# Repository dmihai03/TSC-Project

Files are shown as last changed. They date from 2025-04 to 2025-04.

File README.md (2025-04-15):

# eBook reader - Pacuraru Mihai Dorin
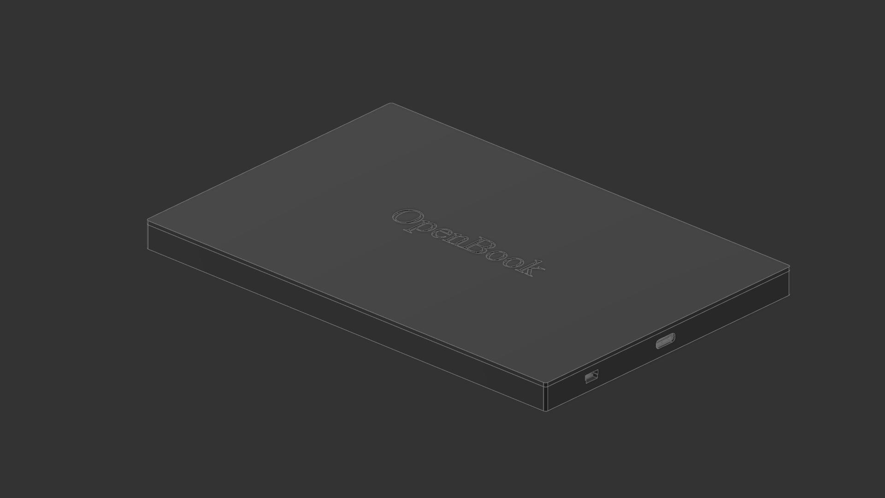
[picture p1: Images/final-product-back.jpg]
final product


This product is an eBook reader that uses an **ESP32-C6** microcontroller powered by an **USB Type-C**.

 Implementation steps:
    - create 2D schematic
    - create 2D PCB, solving routing errors
    - add 3D model to every component 
    - pushed 2D PCB to 3D
    - created 3D model for battery
    - imported display model
    - build the final 3D model of product

---

## Block Diagram
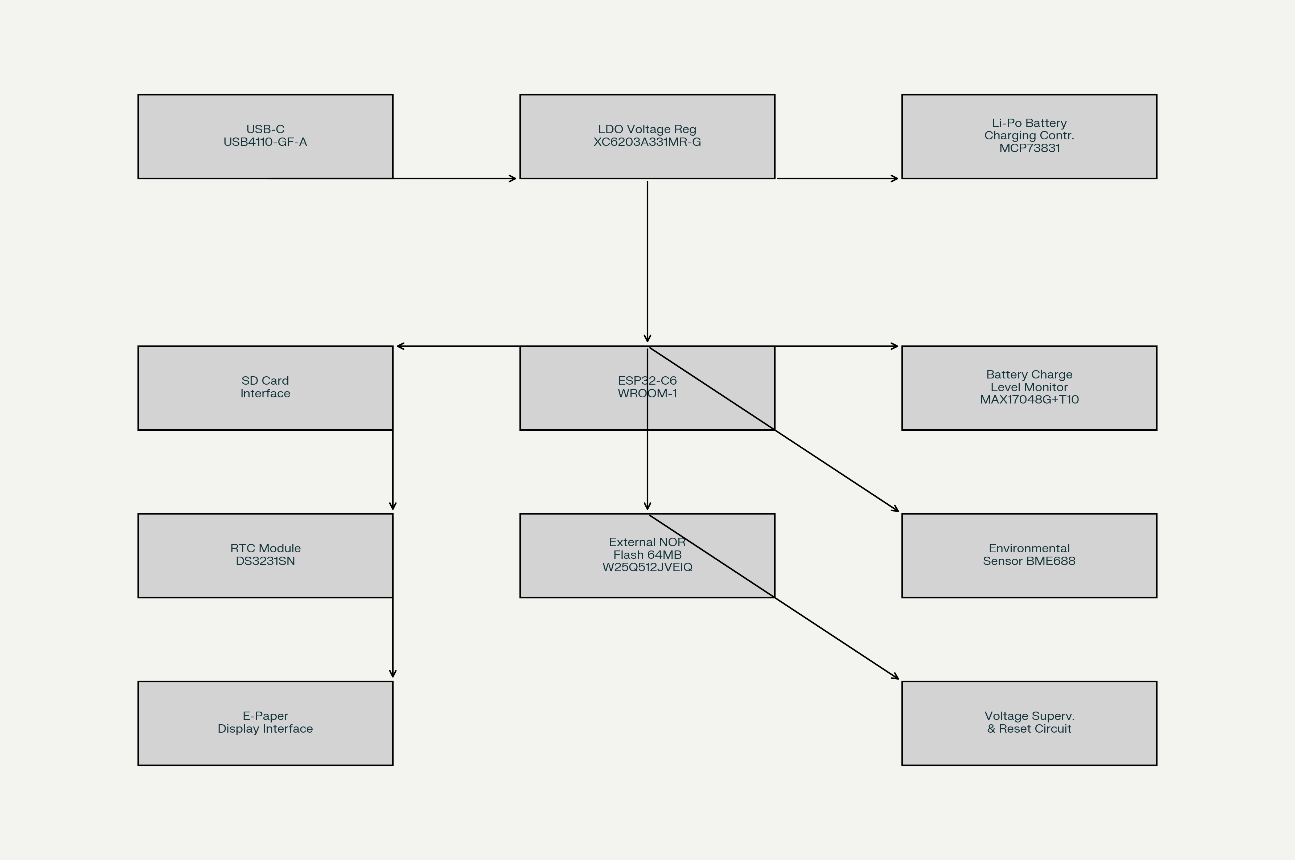
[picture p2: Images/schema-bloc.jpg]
block diagram


---

## Hardware functionalities

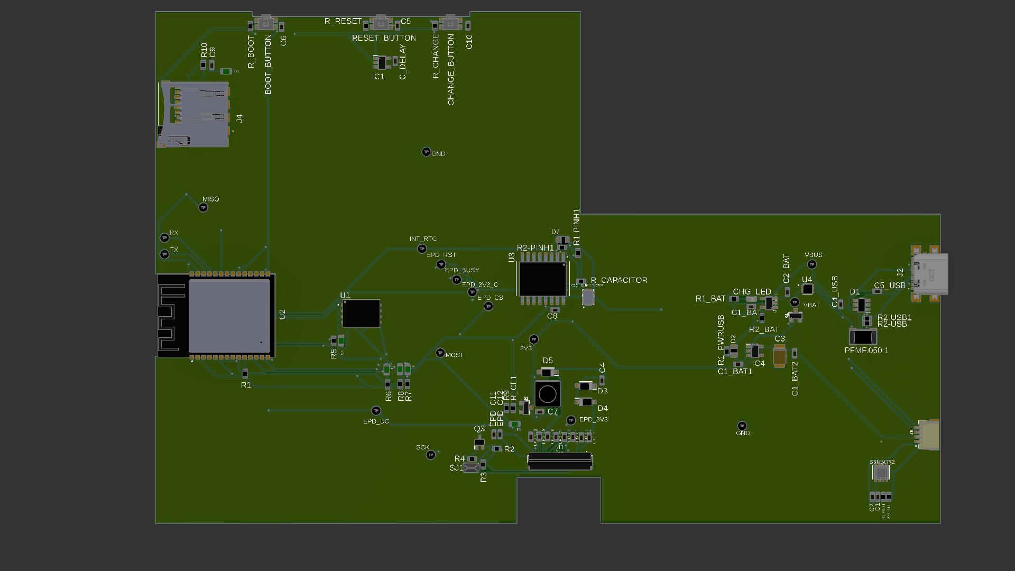
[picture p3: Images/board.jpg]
board


### ESP32-C6 microcontroller

The ESP32-C6 microcontroller has a single core SoC RISC-V that supports:
  - WiFi6, Bluetooth 5, Zigbee and Thread
  - integrated flash memory up to 8 MB
  - 23 GPIO pins
  - SPI, 12C, UART, I2S, USB interfaces support

Charging and energy management:
  - USB-C that uses USB4110-GF-A connector with ESD protection for battery charging
  - LiPo battery that gets charged with the help of MCP73831 controller
  - the integrated circuit MAX17048G+T10 for monitorizing battery charging level via I2C interface

Display system:
  - E-Paper driver interface connected to microcontroller via SPI

Memory:
  - microSD card interface connected via SPI for heavy data

Buttons:
  - BOOT -> the microcontroller enters in bootloader
  - RESET -> general reset
  - I/O CHANGE -> user I/O interactions

### ESP32-C6 pins configuration
| Component | PIN |
|----|----|
|Display SPI | MOSI, CLK, CS, DC |
|BME688 | SDA, SCL, I2C |
|Buttons | GPIO1, GPIO2, GPIO3 |
|USB-C | D+, D-, VBUS |

---
## Bill of Materials (BOM)
| Component | Buy | Datasheet |
| --- | --- | --- |
| PFMF.050.1 | [Retailer](https://ro.mouser.com/ProductDetail/Schurter/PFMF.050.2?qs=1auRipcfynCums5v1iucSA%3D%3D) |  [Datasheet](https://ro.mouser.com/datasheet/2/358/typ_PFMF-1275918.pdf) |
| USB4110-GF-A | [Retailer](https://ro.mouser.com/ProductDetail/GCT/USB4110-GF-A?qs=KUoIvG%2F9IlYiZvIXQjyJeA%3D%3D) | [Datasheet](https://ro.mouser.com/datasheet/2/837/GCT_USB4110_Product_Drawing___20k_cycles-3455479.pdf) |
| USBLC6-2SC6Y | [Retailer](https://ro.mouser.com/ProductDetail/STMicroelectronics/USBLC6-2SC6Y?qs=gNDSiZmRJS%2FOgDexvXkdow%3D%3D) | [Datasheet](https://ro.mouser.com/datasheet/2/389/usblc6_2sc6y-1852505.pdf) |
| SD0805S020S1R0 | [Retailer](https://ro.mouser.com/ProductDetail/KYOCERA-AVX/SD0805S020S1R0?qs=jCA%252BPfw4LHbpkAoSnwrdjw%3D%3D) | [Datasheet](https://ro.mouser.com/datasheet/2/40/schottky-3165252.pdf) |
| DMG2305UX-7 | [Retailer](https://ro.mouser.com/ProductDetail/Diodes-Incorporated/DMG2305UX-7?qs=L1DZKBg7t5F%2FNBHrjfxC%252Bg%3D%3D) | [Datasheet](https://www.diodes.com/assets/Datasheets/DMG2305UX.pdf) |
| XC6220A331MR-G | [Retailer](https://ro.mouser.com/ProductDetail/Torex-Semiconductor/XC6220A331MR-G?qs=AsjdqWjXhJ8ZSWznL1J0gg%3D%3D) | [Datasheet](https://ro.mouser.com/datasheet/2/760/xc6220-3371556.pdf) |
| Condensator 100 uF TANT | [Retailer](https://ro.mouser.com/ProductDetail/KYOCERA-AVX/TAJW107M010RNJ?qs=Wtp%252Bf%2FAeVqIH8v1VxV%252B1Rg%3D%3D) | [Datasheet](https://ro.mouser.com/datasheet/2/40/TAJ-3165264.pdf) |
| 112A-TAAR-R03_ATTEND | [Retailer](https://www.digikey.ro/en/products/detail/attend-technology/112A-TAAR-R03/17633923) | [Datasheet](https://www.attend.com.tw/data/download/file/112A-TAAR-R03_Spec.pdf)
| ESP32-C6-WROOM-1-N8 | [Retailer](https://ro.mouser.com/ProductDetail/Espressif-Systems/ESP32-C6-WROOM-1-N8?qs=8Wlm6%252BaMh8ST02Gmwp74cw%3D%3D) | [Datasheet](https://ro.mouser.com/datasheet/2/891/Espressif_ESP32_C6_WROOM_1__Datasheet_V0_1_PRELIMI-3239987.pdf) |
| MCP73831 | [Retailer](https://ro.mouser.com/ProductDetail/Microchip-Technology/MCP73831T-2ACI-OT?qs=yUQqVecv4qvbBQBGbHx0Mw%3D%3D) | [Datasheet](https://ro.mouser.com/datasheet/2/268/MCP73831_Family_Data_Sheet_DS20001984H-3441711.pdf) |
| CHG_LED | [Retailer](https://store.comet.srl.ro/Catalogue/Product/40478/) | [Datasheet](https://www.snapeda.com/parts/KP-1608SURCK/Kingbright/datasheet/) |
| SI1308EDL-T1-GE3 | [Retailer](https://ro.mouser.com/ProductDetail/Vishay-Semiconductors/SI1308EDL-T1-GE3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) | [Datasheet](https://www.vishay.com/doc?63399) |
| MBR0530 | [Retailer](https://ro.mouser.com/ProductDetail/Micro-Commercial-Components-MCC/MBR0530-T?qs=9VyI4qLX4NTSXkb9ynzJnA%3D%3D) | [Datasheet](https://ro.mouser.com/datasheet/2/258/mcc_mbr0520~mbr0560sod123-1179695.pdf) |
| L1 | [Retailer](https://ro.mouser.com/ProductDetail/Wurth-Elektronik/744043680?qs=PGXP4M47uW6VkZq%252BkzjrHA%3D%3D) | [Datasheet](https://www.we-online.com/components/products/datasheet/744043680.pdf) |
| FH34SRJ-24S-0.5SH_99_ | [Retailer](https://ro.mouser.com/ProductDetail/Hirose-Connector/FH34SRJ-24S-0.5SH99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) | [Datasheet](https://ro.mouser.com/datasheet/2/185/FH34SRJ_24S_0_5SH_99__CL0580_1255_6_99_2DDrawing_0-1615044.pdf) |
| BME688 | [Retailer](https://ro.mouser.com/ProductDetail/Bosch-Sensortec/BME688?qs=IS%252B4QmGtzzqQoVDscqwx3A%3D%3D) | [Datasheet](https://ro.mouser.com/datasheet/2/783/bst_bme688_fl000-2307034.pdf) |
| BD5229G-TR | [Retailer](https://ro.mouser.com/ProductDetail/ROHM-Semiconductor/BD5229G-TR?qs=4kLU8WoGk0vvnhrrYwdszw%3D%3D) | [Datasheet](https://fscdn.rohm.com/en/products/databook/datasheet/ic/power/voltage_detector/bd52xxg-e.pdf) |
| Button | [Retailer](https://ro.mouser.com/ProductDetail/CK/KMR221GULCLFS?qs=u2NJ%252B70r0goBXaNk7IrU0Q%3D%3D) | [Datasheet](https://www.ckswitches.com/media/1479/kmr2.pdf) |
| MAX17048G+T10 | [Retailer](https://ro.mouser.com/ProductDetail/Analog-Devices-Maxim-Integrated/MAX17048G%2bT10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) | [Datasheet](https://ro.mouser.com/datasheet/2/609/MAX17048_MAX17049-3469099.pdf) |
| W25Q512JVEIQ | [Retailer](https://ro.mouser.com/ProductDetail/Winbond/W25Q512JVEIQ?qs=l7cgNqFNU1jw6svr3at6tA%3D%3D) | [Datasheet](https://ro.mouser.com/datasheet/2/949/Winbond_W25Q512JV_Datasheet-3240039.pdf) |
| PGB1010603MR | [Retailer](https://ro.mouser.com/ProductDetail/Littelfuse/PGB1010603MRHF?qs=KvZd0dN2Zg%2FuIq6icj%252BGKA%3D%3D) | [Datasheet](https://www.littelfuse.com/media?itemid=8a337998-d54d-466b-be4e-dc5bcd1f9321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) |
| QWIIC_RIGHT_ANGLE | [Retailer](https://ro.mouser.com/ProductDetail/GCT/USB4110-GF-A?qs=KUoIvG%2F9IlYiZvIXQjyJeA%3D%3D) | [Datasheet](https://ro.mouser.com/datasheet/2/837/GCT_USB4110_Product_Drawing___20k_cycles-3455479.pdf) |
| DS3231SN# | [Retailer](https://ro.mouser.com/ProductDetail/Analog-Devices-Maxim-Integrated/DS3231SN?qs=ffX8NcjNb2RmKAb9wAk9Ug%3D%3D) | [Datasheet](https://ro.mouser.com/datasheet/2/609/DS3231-3421123.pdf) |
| CPH3225A C10_SUPERCAP | [Retailer](https://ro.mouser.com/ProductDetail/Seiko-Semiconductors/CPH3225A?qs=3etwrb1wR%252BhUOph6lAO7eg%3D%3D) | [Datasheet](https://ro.mouser.com/datasheet/2/360/Seiko_Instruments_MicroBattery_E_20230330_2024Jan_-3561061.pdf) |
| Condensator 100nF | [Retailer](https://ro.mouser.com/ProductDetail/KYOCERA-AVX/06033G104ZAT2A?qs=NXubJDmysXJMPmHfVo6Z%252BA%3D%3D) | [Datasheet](https://ro.mouser.com/datasheet/2/40/KGM_Y5V-3223189.pdf) |
| Condensator 4.7uF | [Retailer](https://ro.mouser.com/ProductDetail/KYOCERA-AVX/0402ZD475MAT2A?qs=NBFAU1oqP4W4U2PCPHI0sg%3D%3D) | [Datasheet](https://ro.mouser.com/datasheet/2/40/cx5r_KGM-3223198.pdf) |
| Condensator 10uF | [Retailer](https://ro.mouser.com/ProductDetail/Samsung-Electro-Mechanics/CL10A106KQ8NNNL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) | [Datasheet](https://ro.mouser.com/datasheet/2/585/MLCC-1837944.pdf) |
| Condensator 1uF/50V | [Retailer](https://ro.mouser.com/ProductDetail/KYOCERA-AVX/06035D105MAT2A?qs=k4kUdCzLgS5%252BURKe1SOIeQ%3D%3D) | [Datasheet](https://ro.mouser.com/datasheet/2/40/cx5r_KGM-3223198.pdf) |
| Resistor 10K | [Retailer](https://ro.mouser.com/ProductDetail/Vishay-Beyschlag/MCS0402MD1002BE000?qs=17u8i%2FzlE8%2F9BrAaXkMk1w%3D%3D) | [Datasheet](https://www.vishay.com/doc?28952) |
| Resistor 200 | [Retailer](https://ro.mouser.com/ProductDetail/Vishay-Beyschlag/MCS0402MD2000BE100?qs=3SvaY9RawMJNVte4F12%252BZQ%3D%3D) | [Datasheet](https://www.vishay.com/doc?28952) |
| Resistor 100K | [Retailer](https://ro.mouser.com/ProductDetail/Vishay-Beyschlag/MCT0603PD1003DP500?qs=5aG0NVq1C4wWAn8Ei3OpZA%3D%3D) | [Datasheet](https://www.vishay.com/doc?28916) |
| Resistor 2.2 | [Retailer](https://ro.mouser.com/ProductDetail/SEI-Stackpole/RMCF0402FT2R20?qs=IPgv5n7u5QbBgyl0jwhwsA%3D%3D) | [Datasheet](https://ro.mouser.com/datasheet/2/385/SEI_RMCF_RMCP-3077565.pdf) |
| Resistor 5K1| [Retailer](https://www.venkel.com/part/TFCR0603-16W-K-5690FT) | [Datasheet](https://data.venkel.com/documents/tfcr-series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.) |
| Resistor 2K | [Retailer](https://ro.mouser.com/ProductDetail/Vishay-Beyschlag/MCS04020C2001FE000?qs=wTZ%2FFzl837YG0wIkZJJOwQ%3D%3D) | [Datasheet](https://www.vishay.com/doc?28705) |
| Resistor 0.47 | [Retailer](https://ro.mouser.com/ProductDetail/SEI-Stackpole/CSR0402JKR470?qs=IPgv5n7u5QawIB6nBEt8wA%3D%3D) | [Datasheet](https://ro.mouser.com/datasheet/2/385/SEI_CSR_CSRN-3077593.pdf) |
| Resistor 15 | [Retailer](https://ro.mouser.com/ProductDetail/YAGEO/RT0402FRE0715RL?qs=BXCcY9r%252B08DFFpLSkPOIqQ%3D%3D) | [Datasheet](https://ro.mouser.com/datasheet/2/447/PYu_RT_1_to_0_01_RoHS_L_15-3461507.pdf) |

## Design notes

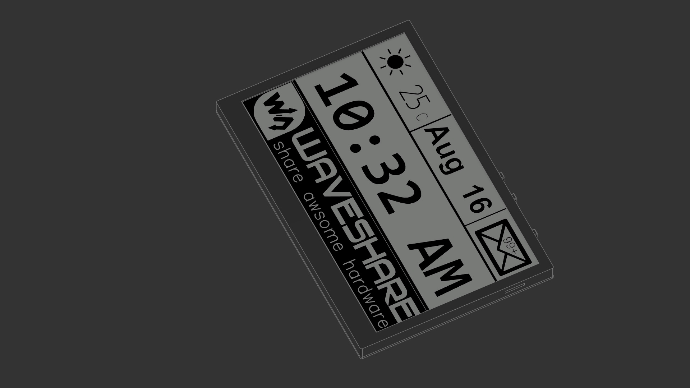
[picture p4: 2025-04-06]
Images/final-product-front.jpg

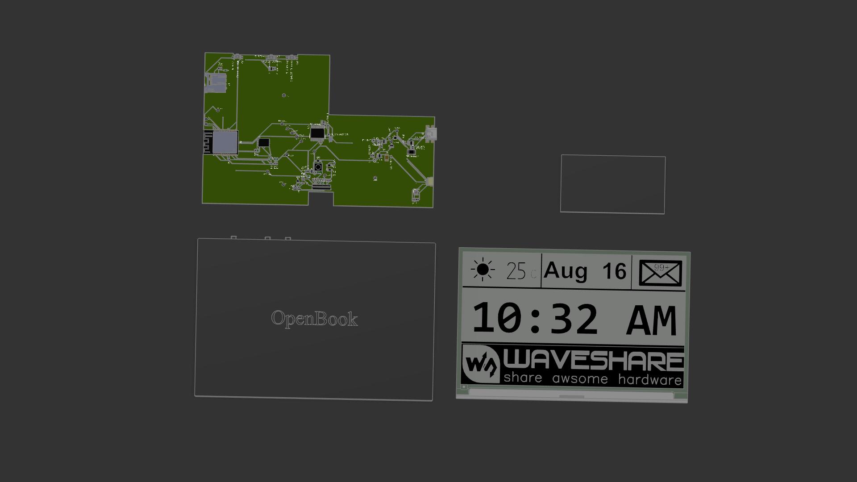
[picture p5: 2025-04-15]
Images/exploded-view.jpg

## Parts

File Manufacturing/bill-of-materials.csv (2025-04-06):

Qty | Value | Device | Package | Parts | Description | ARROW_PART_NUMBER | ARROW_PRICE-STOCK | AVAILABILITY | CENTROID_NOT_SPECIFIED | CHECK_PRICES | COPYRIGHT | DATASHEET | DESCRIPTION | DIGIKEY_DESCRIPTION | DIGIKEY_PART_NUMBER | HEIGHT | LEAD_FREE | MANUFACTURER_NAME | MANUFACTURER_PART_NUMBER | MF | MFR_NAME | MOUSER_PART_NUMBER | MOUSER_PRICE-STOCK | MOUSER_TESTING_PART_NUMBER | MOUSER_TESTING_PRICE-STOCK | MP | MPN | PACKAGE | POPULARITY | PREFIX | PRICE | PROD_ID | PURCHASE-URL | ROHS | SNAPEDA_LINK | SPICEMODEL | SPICEPREFIX | TEMPERATURE_RANGE_HIGH | TEMPERATURE_RANGE_LOW | TP_SIGNAL_NAME | VALUE | VALUE_V
1 |  | ADAFRUIT_LEDCHIP-LED0603 | ADAFRUIT_CHIP-LED0603 | CHG_LED | LED
1 |  | ESP32C6_VARISTORCN1812 | ESP32C6_VARISTOR_CT/CN1812 | PFMF.050.1 | VARISTOR |  |  |  |  |  |  |  |  |  |  |  |  |  |  |  |  |  |  |  |  |  |  |  | 0
1 |  | SAMACSYS_PARTS_USB4110-GF-A | SAMACSYS_PARTS_USB4110GFA | J2 | CONN USB 2.0 TYPE-C R/A SMT |  |  |  |  |  |  |  | CONN USB 2.0 TYPE-C R/A SMT |  |  | 3.26mm |  | GCT (GLOBAL CONNECTOR TECHNOLOGY) | USB4110-GF-A |  |  | 640-USB4110-GF-A | https://www.mouser.co.uk/ProductDetail/GCT/USB4110-GF-A?qs=KUoIvG%2F9IlYiZvIXQjyJeA%3D%3D
1 |  | SJ | SJ | SJ1 | SMD solder JUMPER |  |  |  |  |  |  |  |  |  |  |  |  |  |  |  |  |  |  |  |  |  |  |  | 3
1 | 0.1uF/50V | ESP32_WROVER_EAGLE-LTSPICE_CC0402 | ESP32_WROVER_EAGLE-LTSPICE_C0402 | EPD_C5 | CAPACITOR, European symbol |  |  |  |  |  |  |  |  |  |  |  |  |  |  |  |  |  |  |  |  |  |  |  |  |  |  |  |  |  |  | NONE | C
1 | 0.47 | ESP32_WROVER_EAGLE-LTSPICE_RR0402 | ESP32_WROVER_EAGLE-LTSPICE_R0402 | R3 | RESISTOR, European symbol |  |  |  |  |  |  |  |  |  |  |  |  |  |  |  |  |  |  |  |  |  |  |  |  |  |  |  |  |  |  | NONE | R
1 | 100K | ESP32_WROVER_EAGLE-LTSPICE_RR0402 | ESP32_WROVER_EAGLE-LTSPICE_R0402 | R1_PWRUSB | RESISTOR, European symbol |  |  |  |  |  |  |  |  |  |  |  |  |  |  |  |  |  |  |  |  |  |  |  |  |  |  |  |  |  |  |  | R
1 | 100nF | EAGLE-LTSPICE_CC0402 | ESP32_WROVER_EAGLE-LTSPICE_C0402 | C9 | CAPACITOR, European symbol |  |  |  |  |  |  |  |  |  |  |  |  |  |  |  |  |  |  |  |  |  |  |  |  |  |  |  |  |  |  | NONE | C
8 | 100nF | ESP32_WROVER_EAGLE-LTSPICE_CC0402 | ESP32_WROVER_EAGLE-LTSPICE_C0402 | C1, C2, C4_USB, C5_USB, C6, C8, C10, C_DELAY | CAPACITOR, European symbol |  |  |  |  |  |  |  |  |  |  |  |  |  |  |  |  |  |  |  |  |  |  |  |  |  |  |  |  |  |  | NONE | C
1 | 100uF TANT | RCL_CPOL-EUCT3528 | RCL_CT3528 | C3 | POLARIZED CAPACITOR, European symbol |  |  |  |  |  |  |  |  |  |  |  |  |  |  |  |  |  |  |  |  |  |  |  | 0 |  |  |  |  |  |  |  | C
15 | 10K | ESP32_WROVER_EAGLE-LTSPICE_RR0402 | ESP32_WROVER_EAGLE-LTSPICE_R0402 | R1, R1-PINH, R1-PINH1, R2-PINH, R2-PINH1, R5, R6, R7, R8, R9, R10, R_BOOT, R_CHANGE, R_CL1, R_RESET | RESISTOR, European symbol |  |  |  |  |  |  |  |  |  |  |  |  |  |  |  |  |  |  |  |  |  |  |  |  |  |  |  |  |  |  | NONE | R
1 | 10k | ESP32_WROVER_EAGLE-LTSPICE_RR0402 | ESP32_WROVER_EAGLE-LTSPICE_R0402 | R4 | RESISTOR, European symbol |  |  |  |  |  |  |  |  |  |  |  |  |  |  |  |  |  |  |  |  |  |  |  |  |  |  |  |  |  |  | NONE | R
1 | 10uF | ESP32_WROVER_EAGLE-LTSPICE_CC0402 | ESP32_WROVER_EAGLE-LTSPICE_C0402 | C7 | CAPACITOR, European symbol |  |  |  |  |  |  |  |  |  |  |  |  |  |  |  |  |  |  |  |  |  |  |  |  |  |  |  |  |  |  | NONE | C
1 | 112A-TAAR-R03_ATTEND | 112A-TAAR-R03_ATTEND | 112ATAARR03ATTEND | J4 | Micro SD Card Socket, Push-Push Type, Top Mount, SMT, H=1.83mm, 10u |  |  |  |  |  |  |  | Micro SD Card Socket | Push-Push Type | Top Mount | SMT | H=1.83mm | 10u |  |  | 1.9mm |  | ATTEND | 112A-TAAR-R03 ATTEND
1 | 15 | ESP32_WROVER_EAGLE-LTSPICE_RR0402 | ESP32_WROVER_EAGLE-LTSPICE_R0402 | R_CAPACITOR | RESISTOR, European symbol |  |  |  |  |  |  |  |  |  |  |  |  |  |  |  |  |  |  |  |  |  |  |  |  |  |  |  |  |  |  | NONE | R
1 | 1uF | ESP32_WROVER_EAGLE-LTSPICE_CC0402 | ESP32_WROVER_EAGLE-LTSPICE_C0402 | C5 | CAPACITOR, European symbol |  |  |  |  |  |  |  |  |  |  |  |  |  |  |  |  |  |  |  |  |  |  |  |  |  |  |  |  |  |  | NONE | C
9 | 1uF/50V | ESP32_WROVER_EAGLE-LTSPICE_CC0402 | ESP32_WROVER_EAGLE-LTSPICE_C0402 | EPD_C1, EPD_C2, EPD_C6, EPD_C7, EPD_C8, EPD_C9, EPD_C10, EPD_C11, EPD_C12 | CAPACITOR, European symbol |  |  |  |  |  |  |  |  |  |  |  |  |  |  |  |  |  |  |  |  |  |  |  |  |  |  |  |  |  |  | NONE | C
1 | 2.2 | ESP32_WROVER_EAGLE-LTSPICE_RR0402 | ESP32_WROVER_EAGLE-LTSPICE_R0402 | R2 | RESISTOR, European symbol |  |  |  |  |  |  |  |  |  |  |  |  |  |  |  |  |  |  |  |  |  |  |  |  |  |  |  |  |  |  | NONE | R
1 | 200 | ESP32_WROVER_EAGLE-LTSPICE_RR0402 | ESP32_WROVER_EAGLE-LTSPICE_R0402 | R1_BAT | RESISTOR, European symbol |  |  |  |  |  |  |  |  |  |  |  |  |  |  |  |  |  |  |  |  |  |  |  |  |  |  |  |  |  |  | NONE | R
2 | 20V/4.2A/52mO/1.4W | ESP32_WROVER_SPARKFUN-DISCRETESEMI_MOSFET_PCH-DMG2305UX-7 | ESP32_WROVER_SPARKFUN-DISCRETESEMI_SOT23-3 | Q1, Q2 | P-channel MOSFETs |  |  |  |  |  |  |  |  |  |  |  |  |  |  |  |  |  |  |  |  |  |  |  |  |  |  | TRAN-14388 |  |  |  |  |  |  |  |  | 20V/4.2A/52mO/1.4W
1 | 2K | ESP32_WROVER_EAGLE-LTSPICE_RR0402 | ESP32_WROVER_EAGLE-LTSPICE_R0402 | R2_BAT | RESISTOR, European symbol |  |  |  |  |  |  |  |  |  |  |  |  |  |  |  |  |  |  |  |  |  |  |  |  |  |  |  |  |  |  | NONE | R
2 | 4.7uF | EAGLE-LTSPICE_CC0402 | ESP32_WROVER_EAGLE-LTSPICE_C0402 | C1_BAT1, C1_BAT2 | CAPACITOR, European symbol |  |  |  |  |  |  |  |  |  |  |  |  |  |  |  |  |  |  |  |  |  |  |  |  |  |  |  |  |  |  | NONE | C
2 | 4.7uF | ESP32_WROVER_EAGLE-LTSPICE_CC0402 | ESP32_WROVER_EAGLE-LTSPICE_C0402 | C1_BAT, C2_BAT | CAPACITOR, European symbol |  |  |  |  |  |  |  |  |  |  |  |  |  |  |  |  |  |  |  |  |  |  |  |  |  |  |  |  |  |  | NONE | C
1 | 4.7uF/25V | ESP32_WROVER_EAGLE-LTSPICE_CC0402 | ESP32_WROVER_EAGLE-LTSPICE_C0402 | C4 | CAPACITOR, European symbol |  |  |  |  |  |  |  |  |  |  |  |  |  |  |  |  |  |  |  |  |  |  |  |  |  |  |  |  |  |  | NONE | C
2 | 5k1 | ESP32_WROVER_EAGLE-LTSPICE_RR0402 | ESP32_WROVER_EAGLE-LTSPICE_R0402 | R2-USB, R2-USB1 | RESISTOR, European symbol |  |  |  |  |  |  |  |  |  |  |  |  |  |  |  |  |  |  |  |  |  |  |  |  |  |  |  |  |  |  | NONE | R
1 | 744043680IND_4828-WE-TPC_WRE | 744043680IND_4828-WE-TPC_WRE | IND_4828-WE-TPC_WRE | L1 |  |  |  |  |  |  | Copyright (C) 2024 Ultra Librarian. All rights reserved. |  |  |  |  |  |  |  | 744043680 |  | Wurth Electronics |  |  |  |  |  |  |  |  |  |  |  |  |  |  |  |  |  |  |  |  | 68uH
1 | BD5229G-TR | BD5229G-TR | SOT95P280X125-5N | IC1 | Voltage Detector with Adjustable Delay Time: CMOS processes are utilized to develop high precision, low current consumption CMOS reset ICs that allow arbitrary setting of the delay time. The extensive lineup includes both Nch Open Drain and CMOS output types in a wide range of detection voltages (from 2.3V to 6.0V, in 0.1V steps), enabling selection of the ideal solution based on customer requirements. In addition, the entire series is of course both lead-free and RoHS-compliant. |  |  |  |  |  |  |  | Voltage Detector with Adjustable Delay Time: CMOS processes are utilized to develop high precision | low current consumption CMOS reset ICs that allow arbitrary setting of the delay time. The extensive lineup includes both Nch Open Drain and CMOS output types in a wide range of detection voltages (from 2.3V to 6.0V | in 0.1V steps) | enabling selection of the ideal solution based on customer requirements. In addition | the entire series is of course both lead-free and RoHS-compliant. |  |  | 1.25mm |  | ROHM Semiconductor | BD5229G-TR |  |  | 755-BD5229G-TR | https://www.mouser.co.uk/ProductDetail/ROHM-Semiconductor/BD5229G-TR?qs=4kLU8WoGk0vvnhrrYwdszw%3D%3D
3 | BUTTON_CUSYOMV1 | BUTTON_CUSYOMV1 | MYBUTTON | BOOT_BUTTON, CHANGE_BUTTON, RESET_BUTTON
1 | CPH3225A | CPH3225A | CAPCP3225X100N | C10_SUPERCAP | Cap 0.011F 3.3V 1210 Flat Check availability |  |  | Not in stock |  | https://www.snapeda.com/parts/CPH3225A/Seiko+Instruments/view-part/?ref=eda |  |  | 11 mF (EDLC) Supercapacitor 3.3 V 1210 (3225 Metric) - - |  |  |  |  |  |  | Seiko Instruments |  |  |  |  |  | CPH3225A |  | 1210 Seiko |  |  | None |  | https://www.snapeda.com/api/url_track_click_mouser/?unipart_id=562593&manufacturer=Seiko Instruments&part_name=CPH3225A&search_term=None |  | https://www.snapeda.com/parts/CPH3225A/Seiko+Instruments/view-part/?ref=snap
1 | DS3231SN# | DS3231SN# | SOIC127P1032X265-16N | U3 | Real Time Clock Serial 16-Pin SOIC W T/R Check availability |  |  | In Stock |  | https://www.snapeda.com/parts/DS3231SN%23/Analog+Devices/view-part/?ref=eda |  |  | Extremely Accurate I²C-Integrated RTC/TCXO/Crystal |  |  |  |  |  |  | Analog Devices |  |  |  |  |  | DS3231SN# |  | SOIC-16 Maxim |  |  | None |  | https://www.snapeda.com/api/url_track_click_mouser/?unipart_id=99048&manufacturer=Analog Devices&part_name=DS3231SN#&search_term=None |  | https://www.snapeda.com/parts/DS3231SN%23/Analog+Devices/view-part/?ref=snap
1 | ESP32-C6-WROOM-1-N8 | ESP32-C6-WROOM-1-N8 | XCVR_ESP32-C6-WROOM-1-N8 | U2 | Check availability |  |  | In Stock |  | https://www.snapeda.com/parts/ESP32-C6-WROOM-1-N8/Espressif+Systems/view-part/?ref=eda |  |  | Multiprotocol Modules ESP32-C6 module | Wi-Fi 6 in 2.4 GHz band | Bluetooth 5 | Zigbee 3.0 and Thread. ESP34-WROOM Compatible - ENGINEERING SAMPLE |  |  |  |  |  |  | Espressif Systems |  |  |  |  |  | ESP32-C6-WROOM-1-N8 |  | None |  |  | None |  |  |  | https://www.snapeda.com/parts/ESP32-C6-WROOM-1-N8/Espressif+Systems/view-part/?ref=snap
2 | ESP32_WROVER_AVX---SD0805S020S1R0_AVX_SD0805S020S1R0_0_0AVX_SD0805S020S1R0_0_0 | ESP32_WROVER_AVX---SD0805S020S1R0_AVX_SD0805S020S1R0_0_0AVX_SD0805S020S1R0_0_0 | ESP32_WROVER_AVX---SD0805S020S1R0_AVX_SD0805S020S1R0_0 | D2, D7 | Schottky Barrier Rectifier Diode |  |  |  | No |  |  | http://datasheets.avx.com/schottky.pdf |  | DIODE SCHOTTKY 20V 1A 0805 | 478-7800-1-ND |  | yes |  |  | AVX |  | 581-SD0805S020S1R0 |  |  |  |  |  | 0805 (2012 metric) |  | D |  |  |  | yes |  |  |  | +125°C | -55°C
1 | ESP32_WROVER_BME680_BME680 | ESP32_WROVER_BME680_BME680 | ESP32_WROVER_BME680_PSON80P300X300X100-8N | SENSOR2 | Integrated Environmental Unit |  |  | Unavailable |  |  |  |  | Integrated Environmental Unit |  |  |  |  |  |  | Bosch Sensortec |  |  |  |  |  | BME680 |  | LGA-8 Bosch Tools |  |  | None
1 | ESP32_WROVER_SPARKFUN-IC-POWER_MCP73831 | ESP32_WROVER_SPARKFUN-IC-POWER_MCP73831 | ESP32_WROVER_SPARKFUN-IC-POWER_SOT23-5 | MCP73831 | MCP73831T Li-Ion, Li-Pol Controller |  |  |  |  |  |  |  |  |  |  |  |  |  |  |  |  |  |  |  |  |  |  |  |  |  |  | IC-09995
1 | FH34SRJ-24S-0.5SH_99_ | FH34SRJ-24S-0.5SH_99_ | FH34SRJ24S05SH99 | J1 | (0.50mm) Surface Mount, Right Angle |  |  |  |  |  |  |  | 24 Position FFC | FPC Connector Contacts | (0.50mm) Surface Mount | Right Angle |  |  | 1.1mm |  | Hirose | FH34SRJ-24S-0.5SH(99) |  |  | 798-FH34SRJ24S05SH99 | https://www.mouser.co.uk/ProductDetail/Hirose-Connector/FH34SRJ-24S-0.5SH99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
1 | MAX17048G+T10 | MAX17048G+T10 | SON50P200X200X80-9N | U4 | Check availability |  |  | In Stock |  | https://www.snapeda.com/parts/MAX17048G+T10/Analog+Devices/view-part/?ref=eda |  |  | 3µA 1-Cell/2-Cell Fuel Gauge with ModelGauge |  |  |  |  |  |  | Analog Devices |  |  |  |  |  | MAX17048G+T10 |  | TDFN-8 Maxim |  |  | None |  | https://www.snapeda.com/api/url_track_click_mouser/?unipart_id=329239&manufacturer=Analog Devices&part_name=MAX17048G+T10&search_term=None |  | https://www.snapeda.com/parts/MAX17048G+T10/Analog+Devices/view-part/?ref=snap
3 | MBR0530 | MBR0530 | SOD3716X135N | D3, D4, D5 | ON SEMICONDUCTOR - MBR0530 - DIODE, SCHOTTKY, 0.5A, 30V, SOD-123 |  |  | In Stock |  | https://www.snapeda.com/parts/MBR0530/Onsemi/view-part/?ref=eda |  |  | Diode Schottky 30 V 500mA Surface Mount SOD-123 |  |  |  |  |  |  | ON Semiconductor |  |  |  |  |  | MBR0530 |  | SOD-123-2 ON Semiconductor |  |  | None |  | https://www.snapeda.com/api/url_track_click_mouser/?unipart_id=179458&manufacturer=ON Semiconductor&part_name=MBR0530&search_term=None |  | https://www.snapeda.com/parts/MBR0530/Onsemi/view-part/?ref=snap
6 | PGB1010603MR | PGB1010603MR | DIOC1608X36N | D6, D8, D9, D10, D11, D12 | Check availability |  |  | In Stock |  | https://www.snapeda.com/parts/PGB1010603MR/Littelfuse/view-part/?ref=eda |  |  | 150V (Typ) Clamp - Ipp Tvs Diode Surface Mount 0603 (1608 Metric) |  |  |  |  |  |  | Littelfuse Inc. |  |  |  |  |  | PGB1010603MR |  | 0603 Littelfuse Inc. |  |  | None |  | https://www.snapeda.com/api/url_track_click_mouser/?unipart_id=5659453&manufacturer=Littelfuse Inc.&part_name=PGB1010603MR&search_term=None |  | https://www.snapeda.com/parts/PGB1010603MR/Littelfuse/view-part/?ref=snap
1 | QWIIC_RIGHT_ANGLE | QWIIC_CONNECTORJS-1MM | JST04_1MM_RA | J3 | SparkFun I2C Standard Qwiic Connector |  |  |  |  |  |  |  |  |  |  |  |  |  |  |  |  |  |  |  |  |  |  |  |  |  |  | CONN-13694 |  |  |  |  |  |  |  |  | QWIIC_RIGHT_ANGLE
1 | SI1308EDL-T1-GE3 | SI1308EDL-T1-GE3 | SOT65P210X110-3N | Q3 | MOSFET N-Ch 30V 1.5A TrenchFET SC70 Vishay Si1308EDL-T1-GE3 N-channel MOSFET Transistor, 1.5 A, 30 V, 3-Pin SC-70 |  |  | In Stock |  | https://www.snapeda.com/parts/SI1308EDL-T1-GE3/Vishay+Siliconix/view-part/?ref=eda |  |  | Si1308EDL-T1-GE3 N-channel MOSFET Transistor | 1.5 A | 30 V | 3-Pin SC-70 | Siliconix / Vishay SI1308EDL-T1-GE3 |  |  |  |  |  |  | Vishay Siliconix |  |  |  |  |  | SI1308EDL-T1-GE3 |  | SOT-323 Vishay Semiconductor |  |  | None |  | https://www.snapeda.com/api/url_track_click_mouser/?unipart_id=274603&manufacturer=Vishay Siliconix&part_name=SI1308EDL-T1-GE3&search_term=None |  | https://www.snapeda.com/parts/SI1308EDL-T1-GE3/Vishay+Siliconix/view-part/?ref=snap
17 | TPTP20R | TPTP20R | TP20R | TP1, TP2, TP3, TP4, TP5, TP6, TP7, TP8, TP9, TP10, TP11, TP12, TP13, TP14, TP15, TP16, TP17 | Test pad |  |  |  |  |  |  |  |  |  |  |  |  |  |  |  |  |  |  |  |  |  |  |  | 2
1 | USBLC6-2SC6Y | USBLC6-2SC6Y | SOT95P280X145-6N | D1 | Low Cap. ESD Protection Auto SOT-23-6 STMicroelectronics USBLC6-2SC6Y, Dual Uni-Directional TVS Diode Array, 6-Pin SOT-23 |  |  | In Stock |  | https://www.snapeda.com/parts/USBLC6-2SC6Y/STMicroelectronics/view-part/?ref=eda |  |  | 17V Clamp 5A (8/20µs) Ipp Tvs Diode Surface Mount SOT-23-6 |  |  |  |  |  |  | STMicroelectronics |  |  |  |  |  | USBLC6-2SC6Y |  | SOT-23-6 STMicroelectronics |  |  | None |  |  |  | https://www.snapeda.com/parts/USBLC6-2SC6Y/STMicroelectronics/view-part/?ref=snap
1 | W25Q512JVEIQ | W25Q512JVEIQ | SON127P600X800X80-9N | U1 | Check availability |  |  | In Stock |  | https://www.snapeda.com/parts/W25Q512JVEIQ/Winbond+Electronics/view-part/?ref=eda |  |  | FLASH - NOR Memory IC 512Mb (64M x 8) SPI - Quad I/O 133 MHz 8-WSON (8x6) |  |  |  |  |  |  | Winbond Electronics |  |  |  |  |  | W25Q512JVEIQ |  | Package |  |  | None |  |  |  | https://www.snapeda.com/parts/W25Q512JVEIQ/Winbond+Electronics/view-part/?ref=snap
1 | XC6220A331MR-G | XC6220A331MR-G | SOT95P280X120-5N | IC4 | LDO Voltage Regulators |  |  |  |  |  |  |  | LDO Voltage Regulators |  |  | 1.2mm |  | Torex | XC6220A331MR-G |  |  | 865-XC6220A331MR-G | https://www.mouser.co.uk/ProductDetail/Torex-Semiconductor/XC6220A331MR-G?qs=AsjdqWjXhJ8ZSWznL1J0gg%3D%3D

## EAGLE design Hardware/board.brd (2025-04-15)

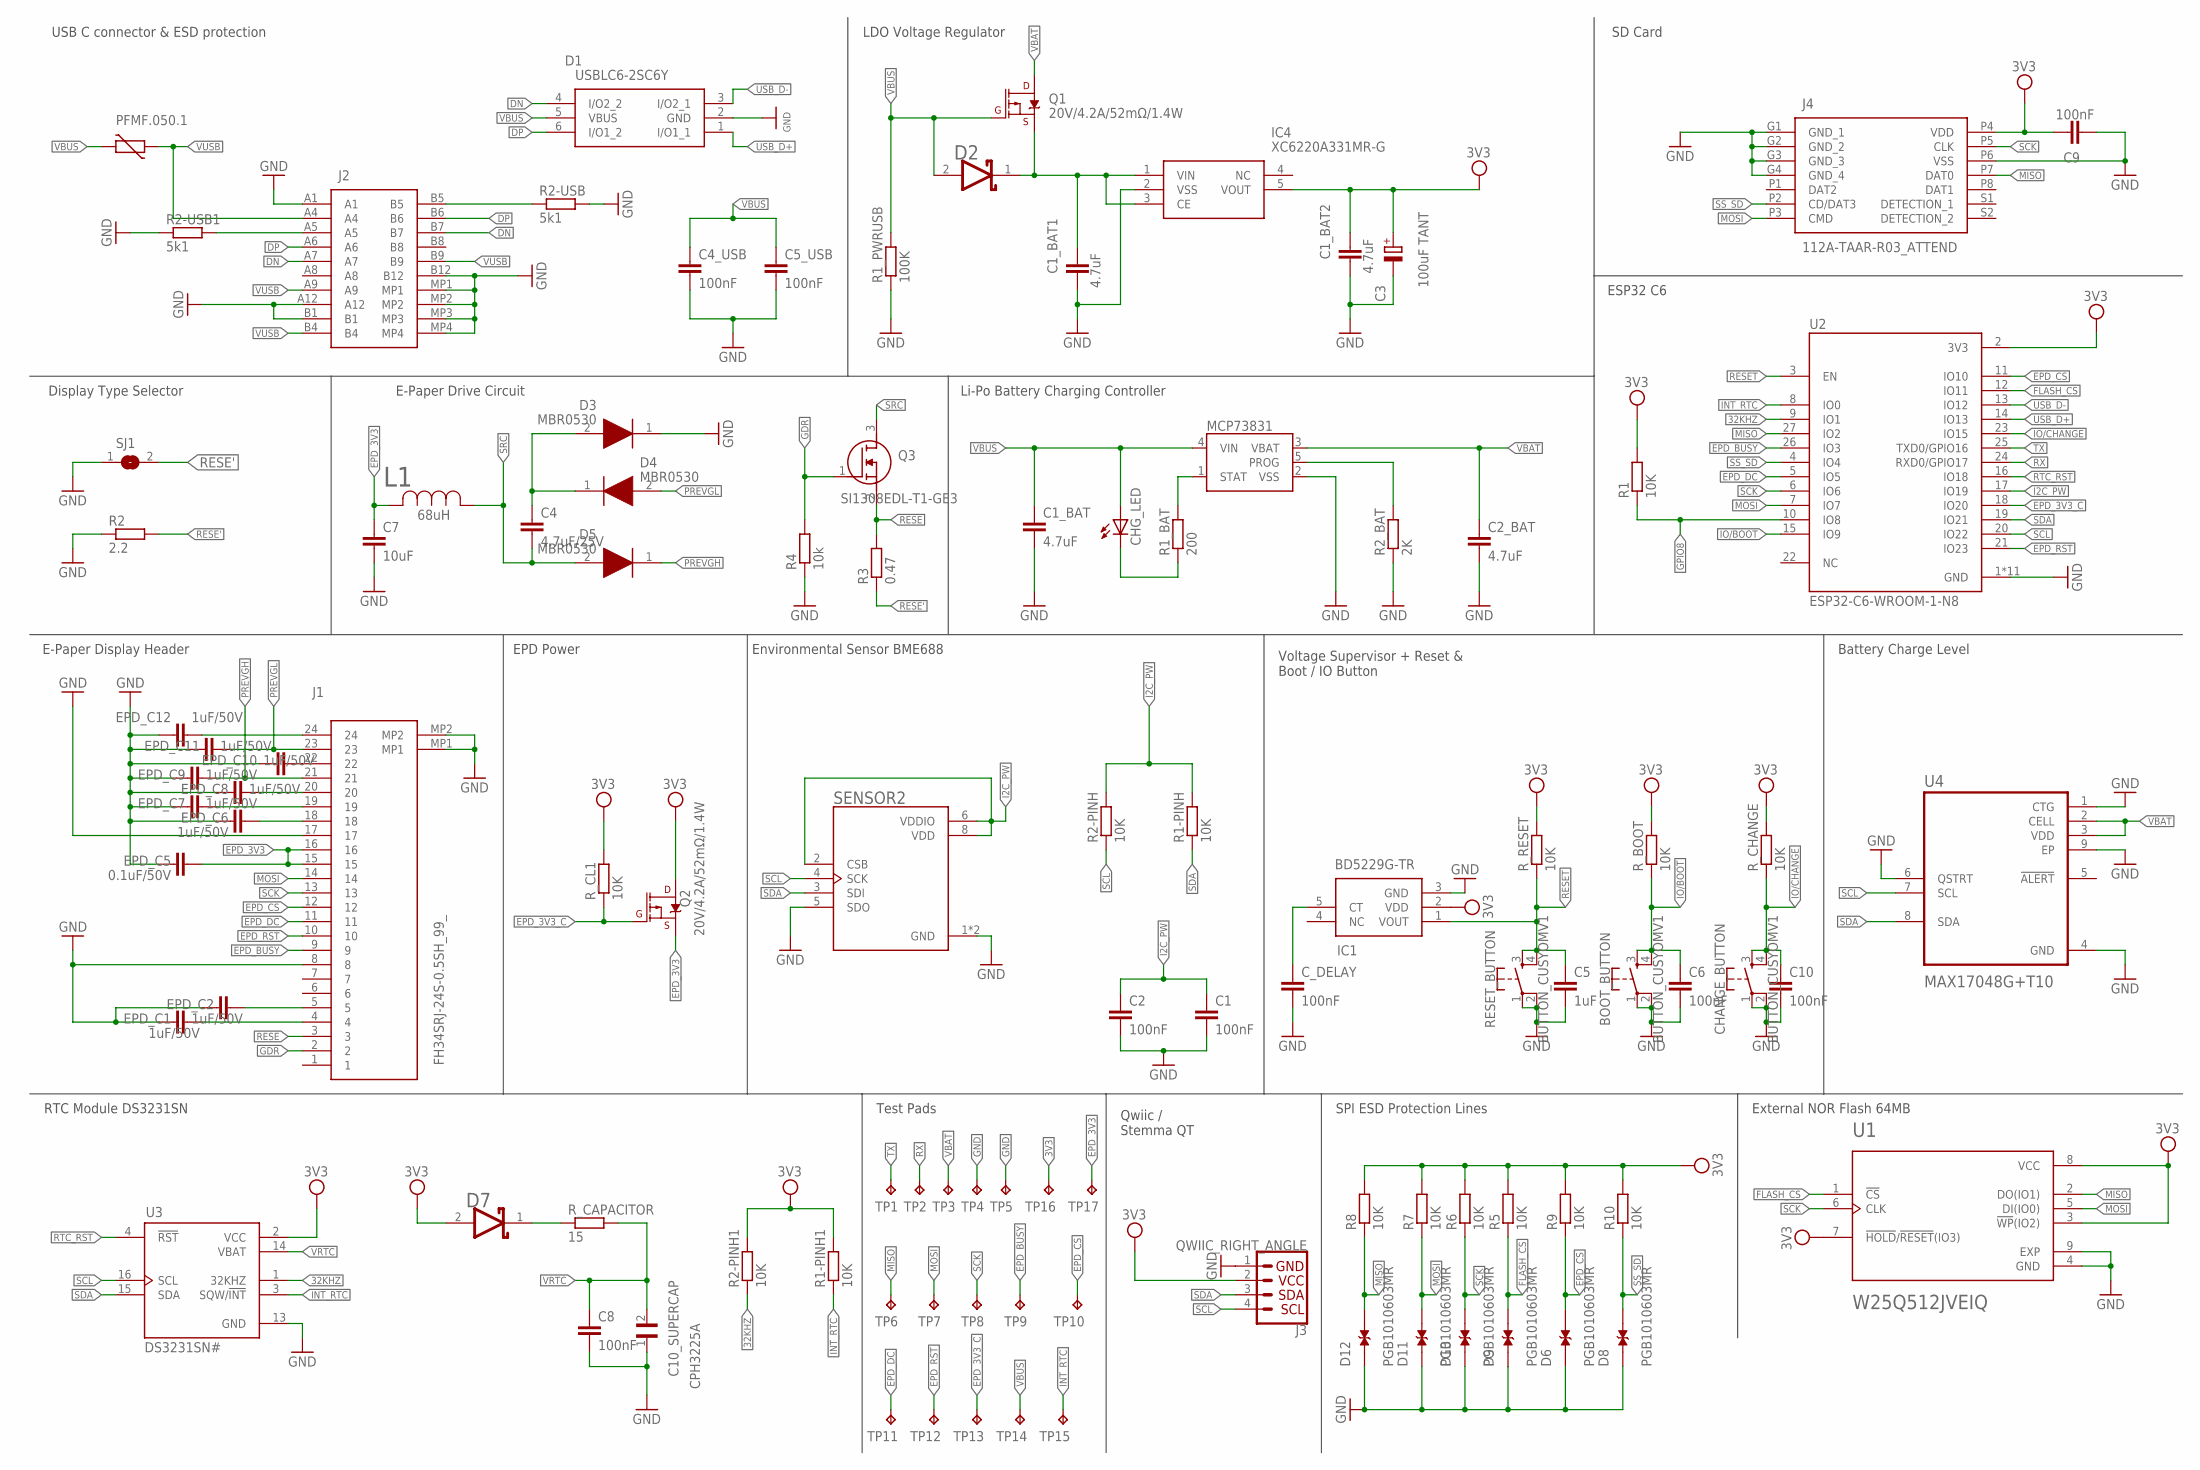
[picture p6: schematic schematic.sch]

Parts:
BOOT_BUTTON: BUTTON_CUSYOMV1; MYBUTTON
C1, C2, C4_USB, C5_USB, C6, C8, C9, C10: 100nF; ESP32_WROVER_EAGLE-LTSPICE_C0402
C1_BAT, C1_BAT1, C1_BAT2, C2_BAT: 4.7uF; ESP32_WROVER_EAGLE-LTSPICE_C0402
C3: 100uF TANT; RCL_CT3528
C4: 4.7uF/25V; ESP32_WROVER_EAGLE-LTSPICE_C0402
C5: 1uF; ESP32_WROVER_EAGLE-LTSPICE_C0402
C7: 10uF; ESP32_WROVER_EAGLE-LTSPICE_C0402
C10_SUPERCAP: CPH3225A; CAPCP3225X100N
CHANGE_BUTTON: BUTTON_CUSYOMV1; MYBUTTON
CHG_LED: ADAFRUIT_LEDCHIP-LED0603; ADAFRUIT_CHIP-LED0603
C_DELAY: 100nF; ESP32_WROVER_EAGLE-LTSPICE_C0402
D1: USBLC6-2SC6Y; SOT95P280X145-6N
D2, D7: ESP32_WROVER_AVX---SD0805S020S1R0_AVX_SD0805S020S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; ESP32_WROVER_AVX---SD0805S020S1R0_AVX_SD0805S020S1R0_0
D3, D4, D5: MBR0530; SOD3716X135N
D6, D8, D9, D10, D11, D12: PGB1010603MR; DIOC1608X36N
EPD_C1, EPD_C2, EPD_C6, EPD_C7, EPD_C8, EPD_C9, EPD_C10, EPD_C11, EPD_C12: 1uF/50V; ESP32_WROVER_EAGLE-LTSPICE_C0402
EPD_C5: 0.1uF/50V; ESP32_WROVER_EAGLE-LTSPICE_C0402
IC1: BD5229G-TR; SOT95P280X125-5N
IC4: XC6220A331MR-G; SOT95P280X120-5N
J1: FH34SRJ-24S-0.5SH_99_; FH34SRJ24S05SH99
J2: SAMACSYS_PARTS_USB4110-GF-A; SAMACSYS_PARTS_USB4110GFA
J3: QWIIC_RIGHT_ANGLE; JST04_1MM_RA
J4: 112A-TAAR-R03_ATTEND; 112ATAARR03ATTEND
L1: 744043680IND_4828-WE-TPC_WRE; IND_4828-WE-TPC_WRE
MCP73831: ESP32_WROVER_SPARKFUN-IC-POWER_MCP73831; ESP32_WROVER_SPARKFUN-IC-POWER_SOT23-5
PFMF.050.1: ESP32C6_VARISTORCN1812; ESP32C6_VARISTOR_CT/CN1812
Q1, Q2: 20V/4.2A/52mΩ/1.4W; ESP32_WROVER_SPARKFUN-DISCRETESEMI_SOT23-3
Q3: SI1308EDL-T1-GE3; SOT65P210X110-3N
R1, R1-PINH, R1-PINH1, R2-PINH, R2-PINH1, R5, R6, R7, R8, R9, R10: 10K; ESP32_WROVER_EAGLE-LTSPICE_R0402
R1_BAT: 200; ESP32_WROVER_EAGLE-LTSPICE_R0402
R1_PWRUSB: 100K; ESP32_WROVER_EAGLE-LTSPICE_R0402
R2: 2.2; ESP32_WROVER_EAGLE-LTSPICE_R0402
R2-USB, R2-USB1: 5k1; ESP32_WROVER_EAGLE-LTSPICE_R0402
R2_BAT: 2K; ESP32_WROVER_EAGLE-LTSPICE_R0402
R3: 0.47; ESP32_WROVER_EAGLE-LTSPICE_R0402
R4: 10k; ESP32_WROVER_EAGLE-LTSPICE_R0402
RESET_BUTTON: BUTTON_CUSYOMV1; MYBUTTON
R_BOOT: 10K; ESP32_WROVER_EAGLE-LTSPICE_R0402
R_CAPACITOR: 15; ESP32_WROVER_EAGLE-LTSPICE_R0402
R_CHANGE: 10K; ESP32_WROVER_EAGLE-LTSPICE_R0402
R_CL1: 10K; ESP32_WROVER_EAGLE-LTSPICE_R0402
R_RESET: 10K; ESP32_WROVER_EAGLE-LTSPICE_R0402
SENSOR2: ESP32_WROVER_BME680_BME680; ESP32_WROVER_BME680_PSON80P300X300X100-8N
SJ1: SJ
TP1, TP2, TP3, TP4, TP5, TP6, TP7, TP8, TP9, TP10, TP11, TP12, TP13, TP14, TP15, TP16, TP17: TPTP20R; TP20R
U1: W25Q512JVEIQ; SON127P600X800X80-9N
U2: ESP32-C6-WROOM-1-N8; XCVR_ESP32-C6-WROOM-1-N8
U3: DS3231SN#; SOIC127P1032X265-16N
U4: MAX17048G+T10; SON50P200X200X80-9N

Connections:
3V3: C1_BAT2.1, C3.+, C9.1, D7.2 (ANODE), IC1.2 (VDD), IC4.5 (VOUT), J3.2, J4.P4 (VDD), Q2.3 (D), R1.2, R1-PINH1.2, R2-PINH1.2, R5.2, R6.2, R7.2, R8.2, R9.2, R10.2, R_BOOT.2, R_CHANGE.2, R_CL1.2, R_RESET.2, TP16.TP, U1.3 (!WP!(IO2)), U1.7 (!HOLD!/!RESET!(IO3)), U1.8 (VCC), U2.2 (3V3), U3.2 (VCC)
32KHZ: R2-PINH1.1, U2.9 (IO1), U3.1 (32KHZ)
DN: D1.4 (I/O2_2), J2.A7, J2.B7
DP: D1.6 (I/O1_2), J2.A6, J2.B6
EPD_3V3: C7.1, EPD_C5.2, J1.15, J1.16, L1.2, Q2.2 (S), TP17.TP
EPD_3V3_C: Q2.1 (G), R_CL1.1, TP13.TP, U2.18 (IO20)
EPD_BUSY: J1.9, TP9.TP, U2.26 (IO3)
EPD_CS: D6.2, J1.12, R9.1, TP10.TP, U2.11 (IO10)
EPD_DC: J1.11, TP11.TP, U2.5 (IO5)
EPD_RST: J1.10, TP12.TP, U2.21 (IO23)
FLASH_CS: D9.2, R5.1, U1.1 (!CS), U2.12 (IO11)
GDR: J1.2, Q3.1 (G), R4.2
GND: BOOT_BUTTON.1, BOOT_BUTTON.2, C1.2, C1_BAT.2, C1_BAT1.2, C1_BAT2.2, C2.2, C2_BAT.2, C3.-, C4_USB.2, C5.2, C5_USB.2, C6.2, C7.2, C8.2, C9.2, C10.2, C10_SUPERCAP.1, CHANGE_BUTTON.1, CHANGE_BUTTON.2, C_DELAY.2, D1.2 (GND), D3.1 (K), D6.1, D8.1, D9.1, D10.1, D11.1, D12.1, EPD_C1.1, EPD_C2.1, EPD_C5.1, EPD_C6.1, EPD_C7.1, EPD_C8.1, EPD_C9.1, EPD_C10.1, EPD_C11.1, EPD_C12.1, IC1.3 (GND), IC4.2 (VSS), J1.8, J1.17, J1.MP1, J1.MP2, J2.A1, J2.A12, J2.B1, J2.B12, J2.MP1, J2.MP2, J2.MP3, J2.MP4, J3.1, J4.G1 (GND_1), J4.G2 (GND_2), J4.G3 (GND_3), J4.G4 (GND_4), J4.P6 (VSS), MCP73831.2 (VSS), R1_PWRUSB.1, R2.1, R2-USB.2, R2-USB1.1, R2_BAT.1, R4.1, RESET_BUTTON.1, RESET_BUTTON.2, SENSOR2.1 (GND), SENSOR2.5 (SDO), SENSOR2.7 (GND), SJ1.1, TP4.TP, TP5.TP, U1.4 (GND), U1.9 (EXP), U2.1 (GND), U2.28 (GND), U2.29_1 (GND), U2.29_2 (GND), U2.29_3 (GND), U2.29_4 (GND), U2.29_5 (GND), U2.29_6 (GND), U2.29_7 (GND), U2.29_8 (GND), U2.29_9 (GND), U3.13 (GND), U4.1 (CTG), U4.4 (GND), U4.6 (QSTRT), U4.9 (EP)
GPIO8: R1.1, U2.10 (IO8)
I2C_PW: C1.1, C2.1, R1-PINH.2, R2-PINH.2, SENSOR2.2 (CSB), SENSOR2.6 (VDDIO), SENSOR2.8 (VDD), U2.17 (IO19)
INT_RTC: R1-PINH1.1, TP15.TP, U2.8 (IO0), U3.3 (SQW/!INT)
IO/BOOT: BOOT_BUTTON.3, BOOT_BUTTON.4, C6.1, R_BOOT.1, U2.15 (IO9)
IO/CHANGE: C10.1, CHANGE_BUTTON.3, CHANGE_BUTTON.4, R_CHANGE.1, U2.23 (IO15)
MISO: D12.2, J4.P7 (DAT0), R8.1, TP6.TP, U1.2 (DO(IO1)), U2.27 (IO2)
MOSI: D11.2, J1.14, J4.P3 (CMD), R7.1, TP7.TP, U1.5 (DI(IO0)), U2.7 (IO7)
unnamed: J2.A5, R2-USB1.2
unnamed: J2.B5, R2-USB.1
unnamed: C1_BAT1.1, D2.1 (CATHODE), IC4.1 (VIN), IC4.3 (CE), Q1.2 (S)
unnamed: MCP73831.5 (PROG), R2_BAT.2
unnamed: EPD_C2.2, J1.5
unnamed: EPD_C1.2, J1.4
unnamed: CHG_LED.C, R1_BAT.1
unnamed: MCP73831.1 (STAT), R1_BAT.2
unnamed: EPD_C12.2, J1.24
unnamed: C_DELAY.1, IC1.5 (CT)
unnamed: EPD_C10.2, J1.22
unnamed: C4.1, D3.2 (A), D4.1 (K)
unnamed: EPD_C8.2, J1.20
unnamed: EPD_C7.2, J1.19
unnamed: EPD_C6.2, J1.18
unnamed: D7.1 (CATHODE), R_CAPACITOR.1
PREVGH: D5.1 (K), EPD_C9.2, J1.21
PREVGL: D4.2 (A), EPD_C11.2, J1.23
RESE: J1.3, Q3.2 (S), R3.2
RESE': R2.2, R3.1, SJ1.2
RESET: C5.1, IC1.1 (VOUT), RESET_BUTTON.3, RESET_BUTTON.4, R_RESET.1, U2.3 (EN)
RTC_RST: U2.16 (IO18), U3.4 (!RST)
RX: TP2.TP, U2.24 (RXD0/GPIO17)
SCK: D10.2, J1.13, J4.P5 (CLK), R6.1, TP8.TP, U1.6 (CLK), U2.6 (IO6)
SCL: J3.4, R2-PINH.1, SENSOR2.4 (SCK), U2.20 (IO22), U3.16 (SCL), U4.7 (SCL)
SDA: J3.3, R1-PINH.1, SENSOR2.3 (SDI), U2.19 (IO21), U3.15 (SDA), U4.8 (SDA)
SRC: C4.2, D5.2 (A), L1.1, Q3.3 (D)
SS_SD: D8.2, J4.P2 (CD/DAT3), R10.1, U2.4 (IO4)
TX: TP1.TP, U2.25 (TXD0/GPIO16)
USB_D+: D1.1 (I/O1_1), U2.14 (IO13)
USB_D-: D1.3 (I/O2_1), U2.13 (IO12)
VBAT: C2_BAT.1, MCP73831.3 (VBAT), Q1.3 (D), TP3.TP, U4.2 (CELL), U4.3 (VDD)
VBUS: C1_BAT.1, C4_USB.1, C5_USB.1, CHG_LED.A, D1.5 (VBUS), D2.2 (ANODE), MCP73831.4 (VIN), PFMF.050.1.2, Q1.1 (G), R1_PWRUSB.2, TP14.TP
VRTC: C8.1, C10_SUPERCAP.2, R_CAPACITOR.2, U3.14 (VBAT)
VUSB: J2.A4, J2.A9, J2.B4, J2.B9, PFMF.050.1.1

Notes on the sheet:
USB C connector & ESD protection
LDO Voltage Regulator
SD Card
Display Type Selector
E-Paper Drive Circuit
Li-Po Battery Charging Controller
ESP32 C6
E-Paper Display Header
EPD Power
Environmental Sensor BME688
Voltage Supervisor + Reset & Boot / IO Button
Battery Charge Level
RTC Module DS3231SN
Test Pads
Qwiic / Stemma QT
SPI ESD Protection Lines
External NOR Flash 64MB

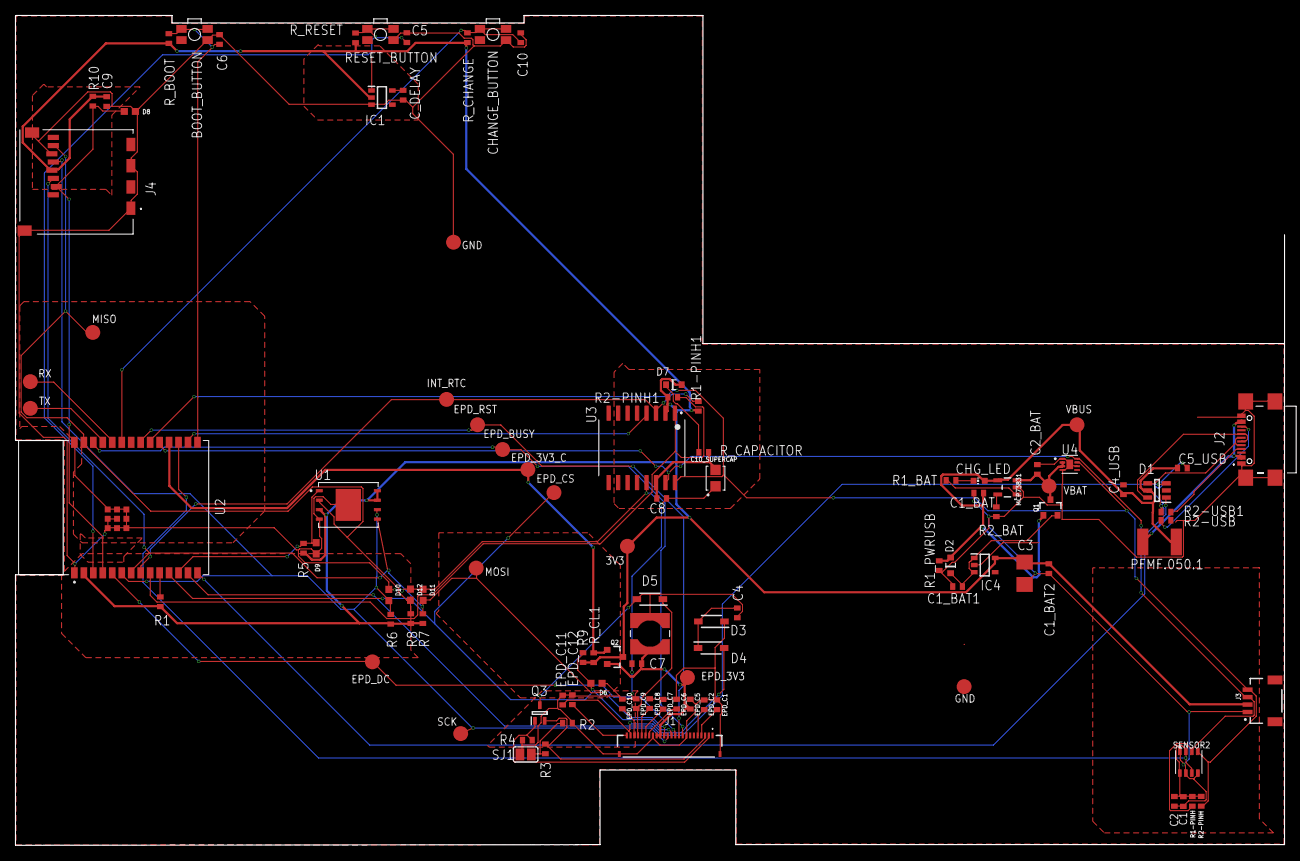
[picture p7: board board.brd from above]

Board: 2 copper layers, 170.2 x 111.3 mm, 103 parts (0 on the bottom side), 55 nets.

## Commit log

2025-03-29 Add schematic
    [schematic.sch]
2025-04-06 Finish first stage w/o additional assigments due to deadline delay
    [board.brd, schematic.sch]
2025-04-06 Add second task
    [bill-of-materials.csv, pick-and-place.csv]
2025-04-15 Fix issues
    [board.brd, schematic.sch]

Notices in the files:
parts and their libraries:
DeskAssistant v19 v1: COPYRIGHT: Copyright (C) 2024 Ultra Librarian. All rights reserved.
